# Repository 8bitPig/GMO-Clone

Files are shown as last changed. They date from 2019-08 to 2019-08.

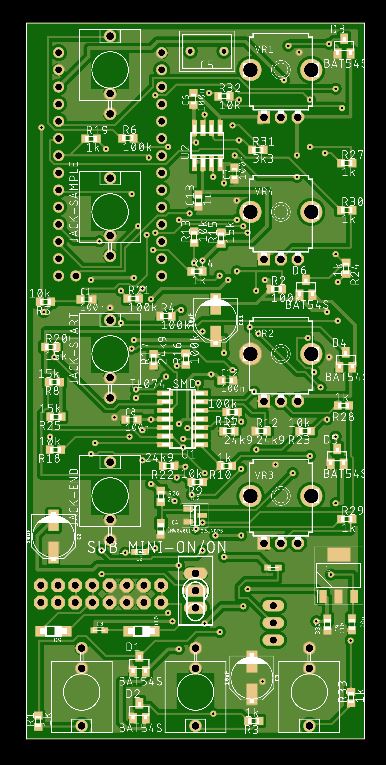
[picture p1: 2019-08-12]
GMO_Clone-pcb_pic.JPG

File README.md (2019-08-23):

# GMO-Clone
a non commercial clone of the Moffenzeef GMO

I am not related to Moffenzeef Modular Company. 
They are not related to the files shared here but allowed me to share them. 

Moffenzeef will NOT do any SUPPORT for this!!! Please do not ask them for help! 

Please do NOT ever SELL the DIY Module you built. 
(CC-BY-NC-SA 4.0)

Before ordering, the files, especially the schemantic should be checked for errors or missing connections by a second pair of eyes please. If you checked them, please let me know. :)

built and tested this version sucessfully on 24th of august 2019.

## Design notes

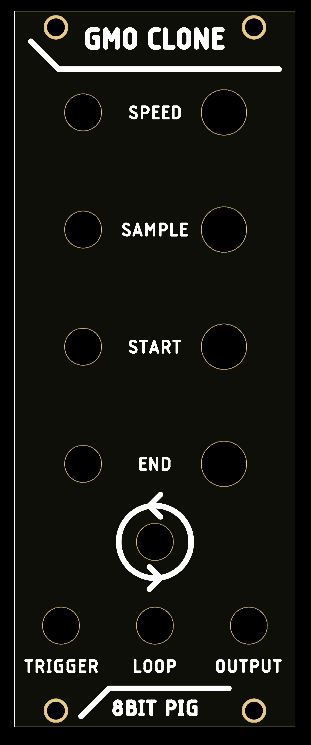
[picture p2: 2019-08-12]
GMO_Clone-Front_Panel_Pic.JPG

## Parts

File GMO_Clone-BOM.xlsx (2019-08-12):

Qty | Value | Device | Package | Parts | Description | DESCRIPTION2 | HEIGHT | MANUFACTURER_NAME | MANUFACTURER_PART_NUMBER | MOUSER_PART_NUMBER | MOUSER_PRICE-STOCK | PROD_ID | RS_PART_NUMBER | RS_PRICE-STOCK | VALUE3
4 |  | 9MM_SNAP-IN_POT_ | 9MM_SNAP-IN_POT | VR1, VR2, VR3, VR4 | 9mm vertical snap-in pot, Alpha / Panasonic style
1 |  | SELECTOR_POWER | SELECTOR_POWER | JP2 | PIN HEADER
3 |  | WE-CBF_0603 | 603 | L1, L2, L3 | SMD EMI Suppression Ferrite Beads
6 | 100k | R-EU_R0603 | R0603 | R2, R4, R6, R11, R16, R21 | RESISTOR, European symbol
1 | 100n | C-EUC0603 | C0603 | C10 | CAPACITOR, European symbol
5 | 100n | C-EUC0603K | C0603K | C1, C6, C7, C8, C12 | CAPACITOR, European symbol
6 | 10k | R-EU_R0603 | R0603 | R5, R9, R13, R18, R23, R32 | RESISTOR, European symbol
3 | 10uF | 47UF-POLAR-PANASONIC_D-35V-20% | PANASONIC_D | C2, C3, C11 | 47ÂµF polarized capacitors |  |  |  |  |  |  | CAP-08478 |  |  | 47uF
4 | 15k | R-EU_R0603 | R0603 | R8, R15, R20, R25 | RESISTOR, European symbol
2 | 1N5819HW | DIODE_DIODE-SOD123 | DIODE_SOD123 | D9, D10 | DIODE
11 | 1k | R-EU_R0603 | R0603 | R1, R3, R10, R14, R19, R24, R27, R28, R29, R30, R33 | RESISTOR, European symbol
2 | 1u | C-EUC0603 | C0603 | C4, C13 | CAPACITOR, European symbol
4 | 24k9 | R-EU_R0603 | R0603 | R7, R12, R17, R22 | RESISTOR, European symbol
1 | 2k | R-EU_R0603 | R0603 | R26 | RESISTOR, European symbol
1 | 330n | C-EUC0603 | C0603 | C9 | CAPACITOR, European symbol
1 | 3k3 | R-EU_R0603 | R0603 | R31 | RESISTOR, European symbol
6 | BAT54S | BAT54S | SOT23 | D1, D2, D3, D4, D5, D6 | Schottky Diodes
1 | LM4040CIM3-2.5_NOPB | LM4040CIM3-2.5_NOPB | SOT95P237X112-3N | IC2 | 100-ppm/C precision micropower shunt voltage reference | 100-ppm/C precision micropower shunt voltage reference | 1.12mm | Texas Instruments | LM4040CIM3-2.5/NOPB | 926-LM4040CIM325NOPB | https://www.mouser.com/Search/Refine.aspx?Keyword=926-LM4040CIM325NOPB |  | 5359600P | http://uk.rs-online.com/web/p/products/5359600P
7 | MISC_JACKTHONK_PJ301M-12 | MISC_JACKTHONK_PJ301M-12 | THONK_PJ301M-12 | JACK-AUDIO_OUT, JACK-END, JACK-LOOP_GATE, JACK-PITCH_CV, JACK-SAMPLE, JACK-START, JACK-TRIGGER | 3.5mm Mono Switching Jack
1 | MKS2C041001F00JA00 | MKS2C041001F00JA00 | MKS2C041001F00JA00 | C5 | Film Capacitors 1.0 uF 63 VDC 5% | Film Capacitors 1.0 uF 63 VDC 5% | 10mm | WIMA | MKS2C041001F00JA00 | 505-MKS2C041001F00JA | https://www.mouser.com/Search/Refine.aspx?Keyword=505-MKS2C041001F00JA
1 | POWER | POWER | POWER_16 | 10_OR_16_PIN1
1 | TEENSY_3.2_DIL+DAC | TEENSY_3.2_DIL+DAC | TEENSY_3.2_DIL+DAC | U$2 | Footprint for Teensy 3.1 or 3.2 board using all pin connections on the outer perimeter
1 | TL072_SMD | TL072_SMD | SO08 | U2 | Generic Dual Op Amp
1 | TL074_SMD | TL074_SMD | SO14 | U1 | Generic Quad Op Amp
1 | TL36PO | TL36PO | TL3XPO | SUB_MINI-ON/ON | TINY SWITCH ON - ON
1 | UA78M05CDCYR | UA78M05CDCYR | SOT230P700X180-4N | IC1 | 500-mA, 25-V, Linear Voltage Regulators | 500-mA, 25-V, Linear Voltage Regulators | 1.8mm | Texas Instruments | UA78M05CDCYR | 595-UA78M05CDCYR | https://www.mouser.com/Search/Refine.aspx?Keyword=595-UA78M05CDCYR

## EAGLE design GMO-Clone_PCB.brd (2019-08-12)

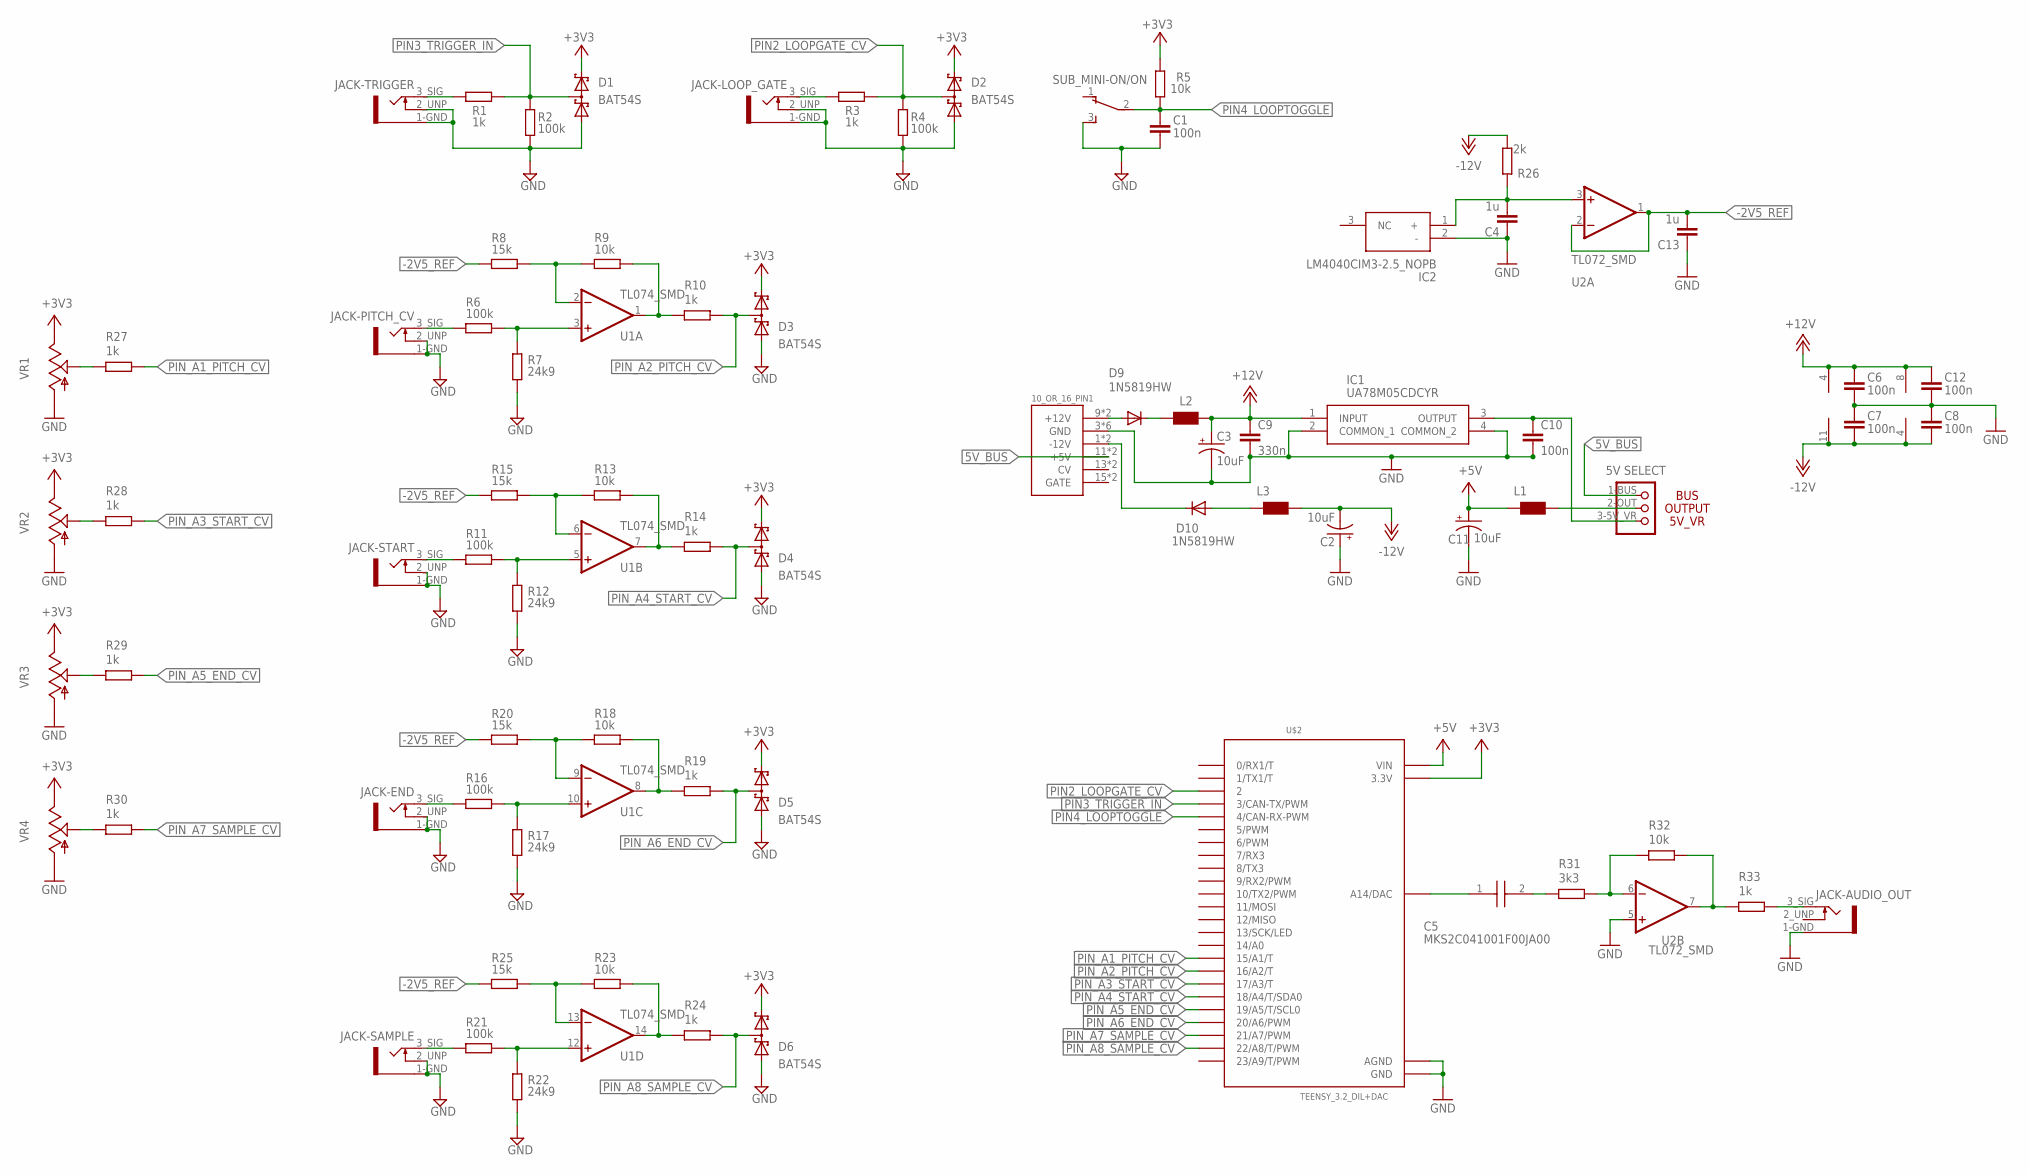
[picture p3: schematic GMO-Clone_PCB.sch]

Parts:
10_OR_16_PIN1: POWER; POWER_16
C1, C6, C7, C8, C12: 100n; C0603K
C2, C3, C11: 10uF; PANASONIC_D
C4, C13: 1u; C0603
C5: MKS2C041001F00JA00
C9: 330n; C0603
C10: 100n; C0603
D1, D2, D3, D4, D5, D6: BAT54S; SOT23
D9, D10: 1N5819HW; DIODE_SOD123
IC1: UA78M05CDCYR; SOT230P700X180-4N
IC2: LM4040CIM3-2.5_NOPB; SOT95P237X112-3N
JACK-AUDIO_OUT: MISC_JACKTHONK_PJ301M-12; THONK_PJ301M-12
JACK-END: MISC_JACKTHONK_PJ301M-12; THONK_PJ301M-12
JACK-LOOP_GATE: MISC_JACKTHONK_PJ301M-12; THONK_PJ301M-12
JACK-PITCH_CV: MISC_JACKTHONK_PJ301M-12; THONK_PJ301M-12
JACK-SAMPLE: MISC_JACKTHONK_PJ301M-12; THONK_PJ301M-12
JACK-START: MISC_JACKTHONK_PJ301M-12; THONK_PJ301M-12
JACK-TRIGGER: MISC_JACKTHONK_PJ301M-12; THONK_PJ301M-12
JP2: SELECTOR_POWER
L1, L2, L3: WE-CBF_0603; 0603
R1, R3, R10, R14, R19, R24, R27, R28, R29, R30, R33: 1k; R0603
R2, R4, R6, R11, R16, R21: 100k; R0603
R5, R9, R13, R18, R23, R32: 10k; R0603
R7, R12, R17, R22: 24k9; R0603
R8, R15, R20, R25: 15k; R0603
R26: 2k; R0603
R31: 3k3; R0603
SUB_MINI-ON/ON: TL36PO; TL3XPO
U1: TL074_SMD; SO14
U2: TL072_SMD; SO08
U$2: TEENSY_3.2_DIL+DAC
VR1, VR2, VR3, VR4: 9MM_SNAP-IN_POT_; 9MM_SNAP-IN_POT

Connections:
5V_BUS: 10_OR_16_PIN1.11 (+5V), 10_OR_16_PIN1.12 (+5V), JP2.1-BUS
+3V3: D1.2 (C2), D2.2 (C2), D3.2 (C2), D4.2 (C2), D5.2 (C2), D6.2 (C2), R5.2, U$2.3.3V, VR1.3 (E), VR2.3 (E), VR3.3 (E), VR4.3 (E)
+5V: C11.+, L1.1, U$2.VIN
+12V: C3.+, C6.1, C9.1, C12.1, IC1.1 (INPUT), L2.2, U1.4 (V+), U2.8 (V+)
-2V5_REF: C13.2, R8.1, R15.1, R20.1, R25.1, U2.1 (OUT), U2.2 (-IN)
-12V: C2.-, C7.2, C8.2, L3.2, R26.2, U1.11 (V-), U2.4 (V-)
GND: 10_OR_16_PIN1.3 (GND), 10_OR_16_PIN1.4 (GND), 10_OR_16_PIN1.5 (GND), 10_OR_16_PIN1.6 (GND), 10_OR_16_PIN1.7 (GND), 10_OR_16_PIN1.8 (GND), C1.2, C2.+, C3.-, C4.1, C6.2, C7.1, C8.1, C9.2, C10.2, C11.-, C12.2, C13.1, D1.1 (A1), D2.1 (A1), D3.1 (A1), D4.1 (A1), D5.1 (A1), D6.1 (A1), IC1.2 (COMMON_1), IC1.4 (COMMON_2), IC2.2 (-), JACK-AUDIO_OUT.1-GND, JACK-END.1-GND, JACK-END.2_UNP (2-UNPLUGGED), JACK-LOOP_GATE.1-GND, JACK-LOOP_GATE.2_UNP (2-UNPLUGGED), JACK-PITCH_CV.1-GND, JACK-PITCH_CV.2_UNP (2-UNPLUGGED), JACK-SAMPLE.1-GND, JACK-SAMPLE.2_UNP (2-UNPLUGGED), JACK-START.1-GND, JACK-START.2_UNP (2-UNPLUGGED), JACK-TRIGGER.1-GND, JACK-TRIGGER.2_UNP (2-UNPLUGGED), R2.1, R4.1, R7.1, R12.1, R17.1, R22.1, SUB_MINI-ON/ON.3 (S), U2.5 (+IN), U$2.AGND, U$2.GND, VR1.1 (A), VR2.1 (A), VR3.1 (A), VR4.1 (A)
unnamed: JACK-LOOP_GATE.3_SIG (3-SIGNAL_IN_OUT), R3.1
unnamed: JACK-TRIGGER.3_SIG (3-SIGNAL_IN_OUT), R1.1
unnamed: JACK-PITCH_CV.3_SIG (3-SIGNAL_IN_OUT), R6.1
unnamed: R9.1, R10.2, U1.1 (OUT)
unnamed: R8.2, R9.2, U1.2 (-IN)
unnamed: JACK-START.3_SIG (3-SIGNAL_IN_OUT), R11.1
unnamed: R6.2, R7.2, U1.3 (+IN)
unnamed: R13.1, R14.2, U1.7 (OUT)
unnamed: R13.2, R15.2, U1.6 (-IN)
unnamed: R11.2, R12.2, U1.5 (+IN)
unnamed: JACK-END.3_SIG (3-SIGNAL_IN_OUT), R16.1
unnamed: R18.1, R19.2, U1.8 (OUT)
unnamed: R18.2, R20.2, U1.9 (-IN)
unnamed: R16.2, R17.2, U1.10 (+IN)
unnamed: JACK-SAMPLE.3_SIG (3-SIGNAL_IN_OUT), R21.1
unnamed: R23.1, R24.2, U1.14 (OUT)
unnamed: R23.2, R25.2, U1.13 (-IN)
unnamed: R21.2, R22.2, U1.12 (+IN)
unnamed: R27.2, VR1.2 (S)
unnamed: R28.2, VR2.2 (S)
unnamed: R29.2, VR3.2 (S)
unnamed: R30.2, VR4.2 (S)
unnamed: C10.1, IC1.3 (OUTPUT), JP2.3-5V_VR (3-VR)
unnamed: 10_OR_16_PIN1.9 (+12V), 10_OR_16_PIN1.10 (+12V), D9.A
unnamed: C5.1, U$2.RESET/DAC (A14/DAC)
unnamed: 10_OR_16_PIN1.1 (-12V), 10_OR_16_PIN1.2 (-12V), D10.C
unnamed: C4.2, IC2.1 (+), R26.1, U2.3 (+IN)
unnamed: C5.2, R31.2
unnamed: R31.1, R32.2, U2.6 (-IN)
unnamed: R32.1, R33.2, U2.7 (OUT)
unnamed: JACK-AUDIO_OUT.3_SIG (3-SIGNAL_IN_OUT), R33.1
unnamed: JP2.2-OUT, L1.2
unnamed: D9.C, L2.1
unnamed: D10.A, L3.1
PIN2_LOOPGATE_CV: D2.3 (C1A2), R3.2, R4.2, U$2.2
PIN3_TRIGGER_IN: D1.3 (C1A2), R1.2, R2.2, U$2.3 (3/CAN-TX/PWM)
PIN4_LOOPTOGGLE: C1.1, R5.1, SUB_MINI-ON/ON.2, U$2.4 (4/CAN-RX-PWM)
PIN_A1_PITCH_CV: R27.1, U$2.15/A1 (15/A1/T)
PIN_A2_PITCH_CV: D3.3 (C1A2), R10.1, U$2.16/A2 (16/A2/T)
PIN_A3_START_CV: R28.1, U$2.17/A3 (17/A3/T)
PIN_A4_START_CV: D4.3 (C1A2), R14.1, U$2.18/A4 (18/A4/T/SDA0)
PIN_A5_END_CV: R29.1, U$2.19/A5 (19/A5/T/SCL0)
PIN_A6_END_CV: D5.3 (C1A2), R19.1, U$2.20/A6 (20/A6/PWM)
PIN_A7_SAMPLE_CV: R30.1, U$2.21/A7 (21/A7/PWM)
PIN_A8_SAMPLE_CV: D6.3 (C1A2), R24.1, U$2.22/A8 (22/A8/T/PWM)

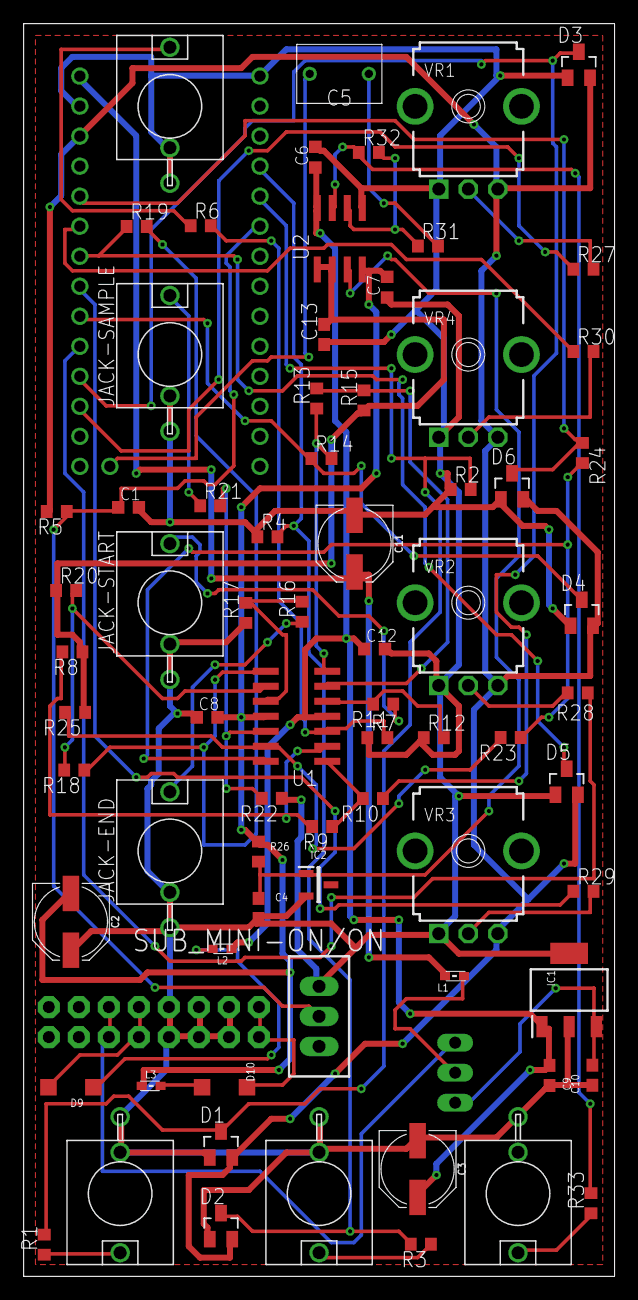
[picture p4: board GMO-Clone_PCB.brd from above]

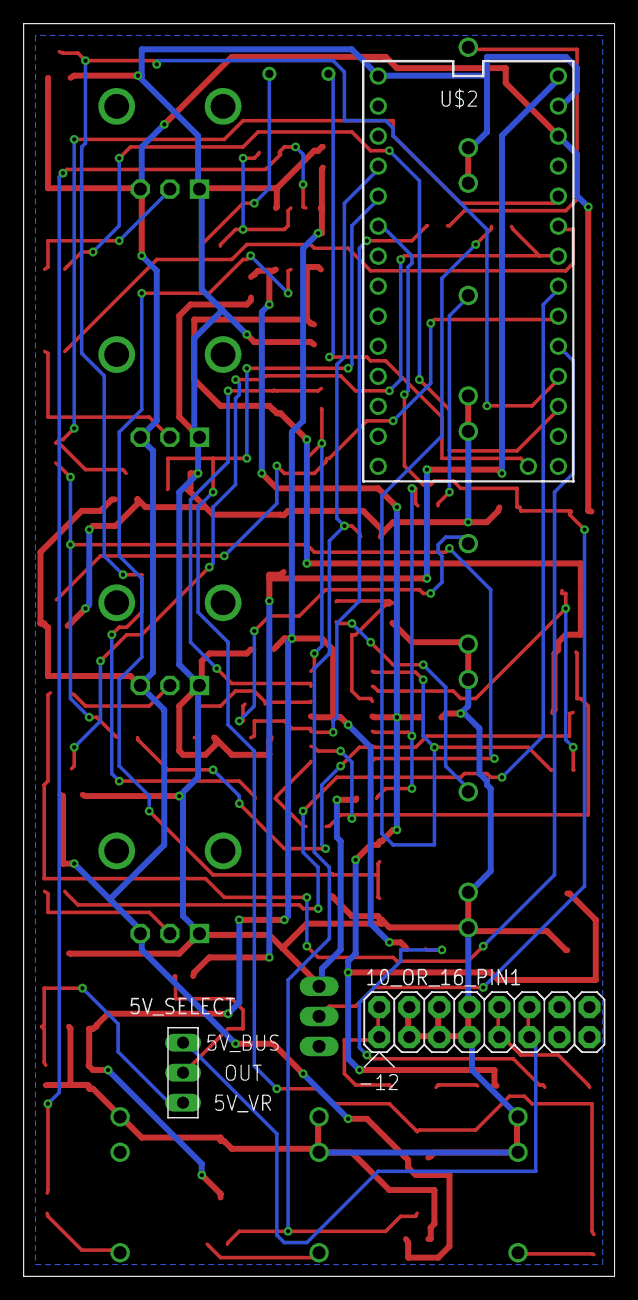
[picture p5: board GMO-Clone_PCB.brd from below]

Board: 2 copper layers, 50.0 x 106.0 mm, 76 parts (3 on the bottom side), 52 nets.

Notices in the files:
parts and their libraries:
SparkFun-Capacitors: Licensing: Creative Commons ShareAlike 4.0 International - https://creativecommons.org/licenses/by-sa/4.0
